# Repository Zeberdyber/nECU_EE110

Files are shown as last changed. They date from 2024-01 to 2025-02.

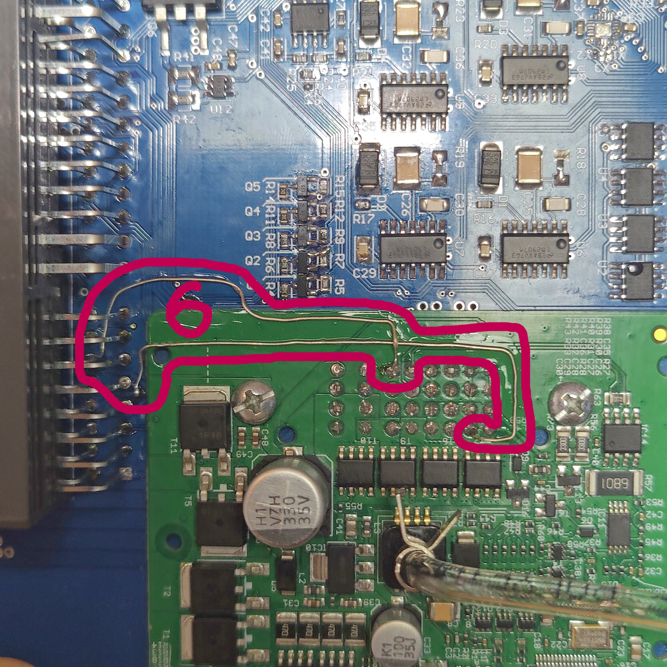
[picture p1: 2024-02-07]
HotFix/hotfix_4.jpg

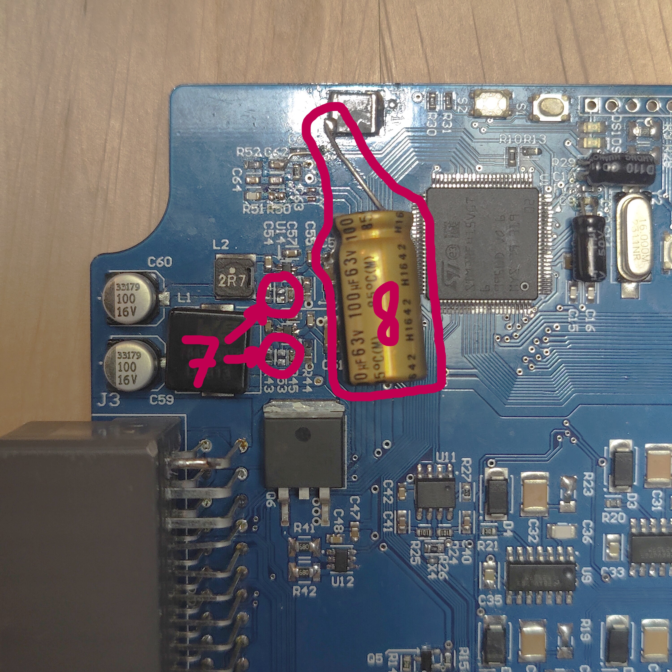
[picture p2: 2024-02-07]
HotFix/hotfix_5.jpg

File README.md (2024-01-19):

# nECU_EE110
Plug and play solution for MaxxECU Mini on EE11x platform. Adds EGT, TC and knock control over CAN.

About
-
Designed for 1996-1999 4E-FE Toyota Corolla EE11x. Fits into stock ECU enclosure, uses the same stock plugs.

It was created to allow remapping and turbo support. Tailored to my needs but basic concepts and solutions may be used to simplify design. 
Knock detection part was my bachelor thesis "Methods for machine analysis of data from the knock combustion sensor of a gasoline engine".

Key Features
-
USB connection for both MaxxECU and onboard STM32 programmer/debbuger.
CAN bus connection allows for external oxygen sensor controller.

Changes compared to stock:
 - USB connector (mandatory),
 - Pneumatic passthrough (mandatory),
 - 24-pin connector #1 [User interface, CAN, Additional IO] (optional),
 - 24-pin connector #2 [EGT sensors, ABS sensors for TC] (optional).

Functionalities in progress
 - 
PCB tested and operational, code is during development or tests:
 - EGT termocouple (testing),
 - Speed sensing (testing and bugfixing),
 - User interface (bugfixing),
 - Knock sensing (optimization and testing),
 - Ignition missfire support (development),
 - Stock oxygen sensor heater (development),
 - Immobilizer communication (scheduled),
 - Additional analog sensors (scheduled),
 - Onboard UART connection (scheduled).

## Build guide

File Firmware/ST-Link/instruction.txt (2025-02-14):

instruction how to setup on board stlink
1. upload binary with "STM32 ST-Link Utility" (old program)
2. check if windows detects it
3. upgrade firmware with "STM32 ST-Link Utility"
4. upgrade firmware with "STM32CubeIDE" (it has access to newest firmwares)

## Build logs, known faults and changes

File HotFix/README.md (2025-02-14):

List of known corrections needed:

1 - USB_ST_N line needs 1.5k pullup to 3.3V
    = new resistor across line via and C202
    
2 - R205 as a pulldown not pullup
    = R205 3.3V leg soldered to C203 GND leg
    
3 - +3V3 not connected to any 3.3V voltage source
    = jumper from C24 to FB102
    
4 - Knock signal DC offset
    = added THT diodes (clipping) and 100k resistors
    
5 - voltage ripple on +5V line
    = 100mH and 470uF added
    
6 - AC signals mixed up
    = jumper wires and cut PCB line
    
7 - Low frequency supply voltage ripple
    = C53 and C58 removal
    
8 - High frequency supply voltage ripple
    = low ESR 100uF capacitor on 3V3 line
    
9 - Missing capacitors of U1
    = 1uF parallel to C9, 1uF on R29 (3V3_nECU line) and C10 (GND line), 4.7uF parallel to C44
10 - IGF no signal
    = Pull down on IGF line (1k)
11 - VSS high noise
    = Pull down on VSS line (1k)

Possible upgrades for future versions:
 - Improve SNR of analog speed signal
 - UART from onboard debbuger
 - MaxxECU direct USB soldering
 - Filtering on input lines on both IGF and VSS signals

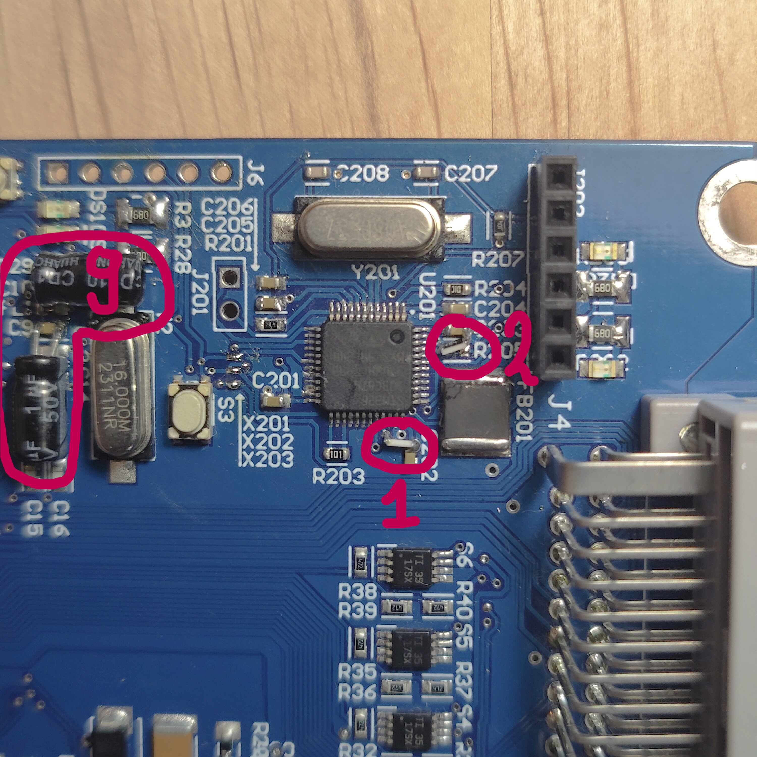
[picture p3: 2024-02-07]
HotFix/hotfix_1.jpg

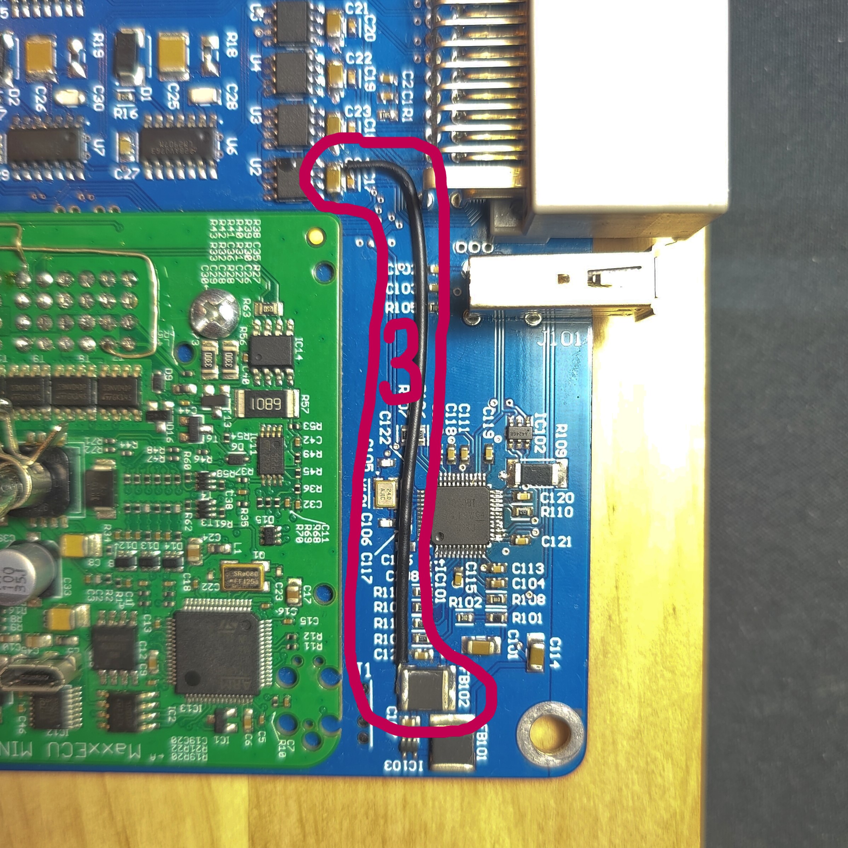
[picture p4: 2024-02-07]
HotFix/hotfix_2.jpg

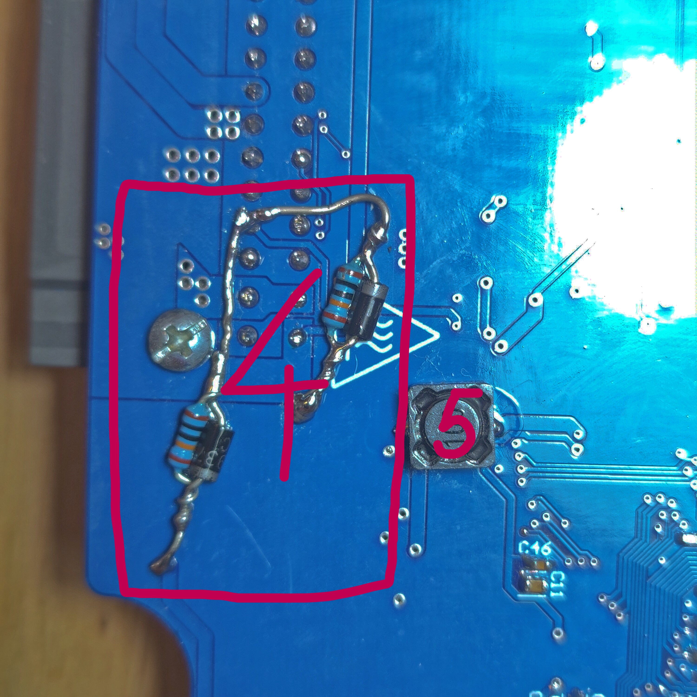
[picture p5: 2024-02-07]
HotFix/hotfix_3.jpg

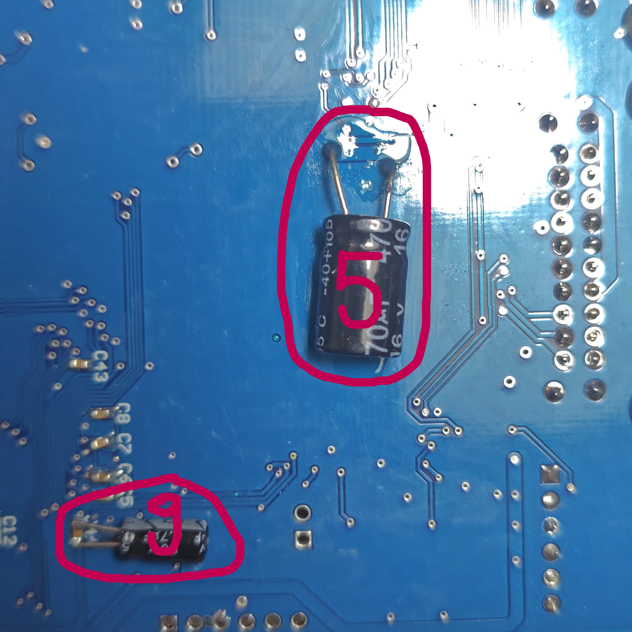
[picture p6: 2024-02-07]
HotFix/hotfix_6.jpg

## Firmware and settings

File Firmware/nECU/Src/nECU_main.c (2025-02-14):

/**
 ******************************************************************************
 * @file    nECU_main.c
 * @brief   This file is the main file of this project. It calls all startup
 *          and loop functions.
 ******************************************************************************
 */

#include "nECU_main.h"

nECU_ProgramBlockData *block;
uint16_t *vrefADC;

static uint8_t max = 0;
#define bar_len 100
static char bar[bar_len] = {0};
static nECU_Delay max_decay;

/* General code */
void nECU_Start(void) // start executing program (mostly in main loop, some in background with interrupts)
{
    bool status = false;
    status |= nECU_Debug_Start(); // MUST BE THE FIRST EXECUTED LINE!!

    if (!nECU_FlowControl_Initialize_Check(D_Main))
    {
        status |= nECU_PC_Start();

        status |= nECU_FLASH_Start(); // initialize FLASH module -> copy from FLASH to RAM
        // nECU_EGT_Start();
        status |= nECU_test(); // perform system and code tests

        status |= Frame0_Start();
        status |= Frame1_Start();
        status |= Frame2_Start();
        status |= nECU_CAN_Start();

        status |= OnBoard_LED_Start();

        if (!status)
            status |= !nECU_FlowControl_Initialize_Do(D_Main);
    }
    if (!nECU_FlowControl_Working_Check(D_Main) && status == false)
    {
        if (!status)
        {
            status |= !nECU_FlowControl_Working_Do(D_Main);
        }
    }
    if (status)
    {
        nECU_FlowControl_Error_Do(D_Main);
    }
    block = nECU_Debug_ProgramBlockData_getPointer_Block(D_Main);
    nECU_InputAnalog_ADC1_Start(ADC1_VREF_ID);
    vrefADC = nECU_ADC1_getPointer(ADC1_VREF_ID);
    nECU_Delay_Set(&max_decay, 1000);
    nECU_Delay_Start(&max_decay);
    nECU_TIM_PWM_Start(TIM_PWM_LED1_ID, 0);
    nECU_TIM_PWM_Start(TIM_PWM_LED2_ID, 0);
}
void nECU_main(void) // main rutine of the program
{
    if (nECU_FlowControl_Error_Check(D_Main))
        while (1)
            HAL_Delay(1);

    if (!nECU_FlowControl_Working_Check(D_Main))
    {
        nECU_FlowControl_Error_Do(D_Main);
        return;
    }

    // call periodic functions
    nECU_Knock_UpdatePeriodic();
    nECU_EGT_Routine();
    nECU_Menu_Routine();

    // update all variables for CAN transmission
    Frame0_PrepareBuffer();
    Frame1_PrepareBuffer();
    Frame2_PrepareBuffer();

    // checks if its time to send packet
    nECU_CAN_TX_CheckTime();

    OnBoard_LED_Update();
    // nECU_Debug_Periodic();

    // nECU_InputAnalog_ADC1_Routine(ADC1_VREF_ID);

    // // nECU_EGT_Routine();

    // nECU_Delay_Update(&max_decay);
    // if (max_decay.done)
    // {
    //     nECU_Delay_Start(&max_decay);
    //     max--;
    // }
    // if (max > block->Update_ticks.difference)
    //     max = (uint8_t)block->Update_ticks.difference;

    // nECU_console_progressBar(bar, bar_len, max);
    // printf("%d\t%s\r", (int)nECU_InputAnalog_ADC1_getValue(ADC1_VREF_ID), bar);
    // fflush(stdout);

    nECU_Debug_ProgramBlockData_Update(D_Main);

    // HAL_Delay(10);

    // test_uart();

    // nECU_Debug_ProgramBlockData_Check();
}
void nECU_Stop(void) // stop all peripherals (no interrupts will generate)
{
    bool status = false;
    status |= nECU_CAN_Stop();
    status |= nECU_Knock_Stop();
    if (!status)
        status |= nECU_FlowControl_Stop_Do(D_Main);

    if (status)
        nECU_FlowControl_Error_Do(D_Main);
}

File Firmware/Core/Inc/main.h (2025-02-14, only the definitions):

#define Lights_ON_Pin GPIO_PIN_4
#define Lights_ON_GPIO_Port GPIOE
#define Fan_ON_Pin GPIO_PIN_5
#define Fan_ON_GPIO_Port GPIOE
#define Cranking_Pin GPIO_PIN_6
#define Cranking_GPIO_Port GPIOE
#define V1_Pin GPIO_PIN_0
#define V1_GPIO_Port GPIOC
#define V2_Pin GPIO_PIN_1
#define V2_GPIO_Port GPIOC
#define V3_Pin GPIO_PIN_2
#define V3_GPIO_Port GPIOC
#define V4_Pin GPIO_PIN_3
#define V4_GPIO_Port GPIOC
#define KNOCK_Pin GPIO_PIN_1
#define KNOCK_GPIO_Port GPIOA
#define MAP_Pin GPIO_PIN_2
#define MAP_GPIO_Port GPIOA
#define Backpressure_Pin GPIO_PIN_3
#define Backpressure_GPIO_Port GPIOA
#define OX_Pin GPIO_PIN_4
#define OX_GPIO_Port GPIOA
#define AI1_Pin GPIO_PIN_5
#define AI1_GPIO_Port GPIOA
#define AI2_Pin GPIO_PIN_6
#define AI2_GPIO_Port GPIOA
#define AI3_Pin GPIO_PIN_7
#define AI3_GPIO_Port GPIOA
#define B1_H_Pin GPIO_PIN_9
#define B1_H_GPIO_Port GPIOE
#define B2_H_Pin GPIO_PIN_11
#define B2_H_GPIO_Port GPIOE
#define B3_H_Pin GPIO_PIN_13
#define B3_H_GPIO_Port GPIOE
#define IGF_Pin GPIO_PIN_12
#define IGF_GPIO_Port GPIOD
#define VSS_Pin GPIO_PIN_13
#define VSS_GPIO_Port GPIOD
#define B1_S_Pin GPIO_PIN_6
#define B1_S_GPIO_Port GPIOC
#define B2_S_Pin GPIO_PIN_7
#define B2_S_GPIO_Port GPIOC
#define B3_S_Pin GPIO_PIN_8
#define B3_S_GPIO_Port GPIOC
#define IMO_Pin GPIO_PIN_9
#define IMO_GPIO_Port GPIOA
#define IMI_Pin GPIO_PIN_10
#define IMI_GPIO_Port GPIOA
#define OX_PWM_Pin GPIO_PIN_15
#define OX_PWM_GPIO_Port GPIOA
#define PC_TX_Pin GPIO_PIN_10
#define PC_TX_GPIO_Port GPIOC
#define PC_RX_Pin GPIO_PIN_11
#define PC_RX_GPIO_Port GPIOC
#define T4_CS_Pin GPIO_PIN_3
#define T4_CS_GPIO_Port GPIOD
#define T3_CS_Pin GPIO_PIN_4
#define T3_CS_GPIO_Port GPIOD
#define T2_CS_Pin GPIO_PIN_5
#define T2_CS_GPIO_Port GPIOD
#define T1_CS_Pin GPIO_PIN_6
#define T1_CS_GPIO_Port GPIOD
#define LED1_Pin GPIO_PIN_8
#define LED1_GPIO_Port GPIOB
#define LED2_Pin GPIO_PIN_9
#define LED2_GPIO_Port GPIOB
#define S1_Pin GPIO_PIN_0
#define S1_GPIO_Port GPIOE
#define S2_Pin GPIO_PIN_1
#define S2_GPIO_Port GPIOE

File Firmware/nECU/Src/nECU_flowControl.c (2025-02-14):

/**
 ******************************************************************************
 * @file    nECU_flowControl.c
 * @brief   This file provides code for debugging code using onboard buttons,
 *          and LEDs.
 ******************************************************************************
 */

#include "nECU_flowControl.h"

nECU_ProgramBlockData Debug_Status_List[D_ID_MAX] = {0}; // array of all nECU_ProgramBlockData variables

static char const *const D_ID_Strings[D_ID_MAX] = {
    // nECU_adc.c
    [D_ADC1] = "ADC1",
    [D_ADC2] = "ADC2",
    [D_ADC3] = "ADC3",
    // nECU_button.c
    [D_Button_Red] = "Button RED",
    [D_Button_Orange] = "Button ORANGE",
    [D_Button_Green] = "Button Green",
    // nECU_can.c
    [D_CAN_TX] = "CAN TX",
    [D_CAN_RX] = "CAN RX",
    // nECU_data_processing.c
    [D_Data_Processing] = "Data Processing",
    // nECU_debug.c
    [D_Debug] = "Debug Main",
    [D_Debug_Que] = "Debug Que",
    // nECU_EGT.c
    [D_EGT1] = "EGT1",
    [D_EGT2] = "EGT2",
    [D_EGT3] = "EGT3",
    [D_EGT4] = "EGT4",
    // nECU_flash.c
    [D_Flash] = "Flash",
    // nECU_frames.c
    [D_Frame_Speed_ID] = "CAN Frame 0",
    [D_Frame_EGT_ID] = "CAN Frame 1",
    [D_Frame_Stock_ID] = "CAN Frame 2",
    // nECU_Input_Analog.c
    [D_ANALOG_MAP] = "Stock MAP",
    [D_ANALOG_BackPressure] = "BackPressure",
    [D_ANALOG_OX] = "OX analog sensor",
    [D_ANALOG_AI_1] = "Additional Analog Input 1",
    [D_ANALOG_AI_2] = "Additional Analog Input 2",
    [D_ANALOG_AI_3] = "Additional Analog Input 3",
    [D_ANALOG_MCUTemp] = "nECU temperature",
    [D_ANALOG_VREF] = "Reference voltage sensing",
    // nECU_Input_Frequency.c
    [D_VSS] = "Stock VSS",
    [D_IGF] = "Stock Ignition Fault Detection",
    [D_Input_Frequency] = "Frequency Input",
    // nECU_Knock.c
    [D_Knock] = "Stock Knock sensing",
    // nECU_main.c
    [D_Main] = "Main Loop",
    // nECU_menu.c
    [D_Tacho] = "Tacho Display",
    [D_Menu] = "Button Menu",
    // nECU_OnBoardLED.c
    [D_OnboardLED] = "LED on PCB",
    // nECU_PC.c
    [D_PC] = "PC communication",
    // nECU_Speed.c
    [D_ANALOG_SS1] = "ABS Speed Sensor 1",
    [D_ANALOG_SS2] = "ABS Speed Sensor 2",
    [D_ANALOG_SS3] = "ABS Speed Sensor 3",
    [D_ANALOG_SS4] = "ABS Speed Sensor 4",
    // nECU_stock.c
    [D_DigiInput_CRANKING] = "Digital Input Cranking",
    [D_DigiInput_FAN_ON] = "Digital Input Radiator Fan",
    [D_DigiInput_LIGHTS_ON] = "Digital Input Headlights",
    [D_DigiInput_VSS] = "Digital Input VSS (Edge Sensing)",
    [D_DigiInput_IGF] = "Digital Input IGF (Edge Sensing)",
    [D_OX] = "Stock Lambda sensor",
    // nECU_tim.c
    [D_TIM_PWM_BUTTON] = "Button PWM Timer",
    [D_TIM_PWM_OX] = "Stock Lambda Heater PWM Timer",
    [D_TIM_IC_BUTTON] = "Button IC Timer",
    [D_TIM_IC_FREQ] = "Frequency Input Timer",
    [D_TIM_ADC_KNOCK] = "Knock ADC Timer",
    [D_TIM_FRAME] = "Frame Timer",
    [D_TIM_PWM_LED1] = "OnBoard LED1 Timer",
    [D_TIM_PWM_LED2] = "OnBoard LED2 Timer",
}; // List of strings of corresponding IDs

/* Program Block */
void nECU_Debug_ProgramBlock_Init(void) // Initialize 'ProgramBlock' tracking
{
    // Initialize structures
    for (uint8_t index = 0; index < D_ID_MAX; index++)
    {
        nECU_Debug_ProgramBlockData_Clear(&Debug_Status_List[index]);
    }
    // Configure timeout values
}
static void nECU_Debug_ProgramBlockData_Clear(nECU_ProgramBlockData *inst) // Clear structure 'ProgramBlockData'
{
    memset(inst, 0, sizeof(nECU_ProgramBlockData));
    inst->Status = D_BLOCK_STOP;
    nECU_TickTrack_Init(&(inst->Update_ticks));
    inst->timeout_value = PROGRAMBLOCK_TIMEOUT_DEFAULT * (1000 / (inst->Update_ticks.convFactor));
}
void nECU_Debug_ProgramBlockData_Update(nECU_Module_ID ID) // Update tick tracking and check for timeout
{
    nECU_ProgramBlockData *inst = &Debug_Status_List[ID];
    nECU_TickTrack_Update(&(inst->Update_ticks));
    if (inst->Update_ticks.difference > inst->timeout_value)
    {
        inst->Status |= D_BLOCK_ERROR;
    }
}
void nECU_Debug_ProgramBlockData_Check(void) // Perform error check for all blocks
{
    uint8_t single_result;
    // Perform for each one
    for (uint8_t index = 0; index < D_ID_MAX; index++)
    {
        single_result = nECU_Debug_ProgramBlockData_Check_Single(&Debug_Status_List[index]);
        if (single_result == 2) // save error if major
        {
            nECU_Debug_error_mesage temp;
            float error_message = index;    // copy index to new float
            error_message /= 100;           // move index after 'dot'
            error_message += HAL_GetTick(); // add current tick to the value

            /* Example of how message will work:
                Error detected at index 31, current tick 123456
                error_message == 123456.31;
            */
            nECU_Debug_Message_Set(&temp, error_message, nECU_ERROR_PROGRAMBLOCK);
        }
    }
}
static uint8_t nECU_Debug_ProgramBlockData_Check_Single(nECU_ProgramBlockData *inst) // returns true if issue in given instance
{
    /* Return value scheme:
        0 - OK
        1 - NOK -> low priority
        2 - NOK -> persistent error
    */
    uint8_t result = 0;

    if (inst->Status & D_BLOCK_ERROR)
    {
        result = 1;
        if (inst->Status & D_BLOCK_ERROR_OLD) // if error was already in memor (major error)
        {
            result = 2;
        }
        inst->Status |= D_BLOCK_ERROR_OLD; // store error to memory
        inst->Status -= D_BLOCK_ERROR;
    }

    return result;
}
nECU_ProgramBlockData *nECU_Debug_ProgramBlockData_getPointer_Block(nECU_Module_ID ID) // returns pointer to given ID program block
{
    return &(Debug_Status_List[ID]);
}
uint32_t *nECU_Debug_ProgramBlockData_getPointer_Diff(nECU_Module_ID ID) // returns pointer to time difference
{
    return &(Debug_Status_List[ID].Update_ticks.difference);
}
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

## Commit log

2024-01-24 Files renamed, SPI minor cleanup
2024-01-29 ADC structures added
2024-01-30 EGT SPI moved to spi file, TODO updated
2024-02-01 ADC averaging and smoothing added
2024-02-04 Added new timer general functions and some watchdog functionality
2024-02-07 First startup on new code (no crash)
    [nECU_EGT.c, nECU_adc.c, nECU_button.c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]
2024-02-07 ADC sampling fixed
2024-02-07 SPI debugging
2024-02-23 Timer structure implemented, CAN frames unified
2024-02-24 Loopcounter, watchdog timer pointers
2024-02-25 Internal temperature timing with nECU_delay()
2024-02-25 Internal temperature checking in Debug file
2024-03-01 EGT sensor debugging
2024-03-02 SPI recive errors fixed
    [nECU_EGT.c, nECU_Firmware.ioc, nECU_spi.c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]
2024-03-04 Debug que and que saving
2024-03-04 OX heater implemented
2024-03-05 EGT SPI simplified and SPI error detection added
    [nECU_EGT.c, nECU_debug.c, nECU_flash.h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]
2024-03-19 Testing done, code fixes
    [nECU_EGT.c, nECU_can.c, nECU_main.c]
2024-03-20 CAN and SPI error checking
    [nECU_can.c, nECU_debug.c, nECU_types.h]
2024-03-27 Button input fixed, flash testing
    [nECU_button.c, nECU_button.h, nECU_debug.c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]
2024-04-21 MAP calibration
2024-04-22 htim4 Input Capture fixed, VSS smoothing added
    [nECU_adc.c, nECU_adc.h, nECU_main.c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]
2024-04-22 Data smoothing tested and corrected
    [nECU_data_processing.c, nECU_main.c]
2024-04-22 Flash saving rewritten (fixed)
    [nECU_flash.c, nECU_flash.h, nECU_tests.c]
2024-04-23 VSS zero detection and signal filtering
2024-04-30 Onboard UART tested, VSS calibrated
2024-04-30 UART file mess cleaned up
2024-05-04 OnBoardLED files added, LED handling rewritten, que added to easily stack animations
2025-01-30 Started UART terminal debugging messages. -Wall -Wextra compiler options added
2025-02-12 flowControl created
2025-02-13 CAN RX: seperate messages for variables, bugfixes
    [nECU_can.c, nECU_frames.c, nECU_main.c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]
2025-02-14 VSS tested; ioc update, onboard LEDs moved to TIMs

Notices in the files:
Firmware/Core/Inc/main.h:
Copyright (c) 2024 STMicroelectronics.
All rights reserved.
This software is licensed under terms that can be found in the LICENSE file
